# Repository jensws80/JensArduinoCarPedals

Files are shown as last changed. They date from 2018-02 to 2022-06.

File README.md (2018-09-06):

# JensArduinoCarPedals

Car Simulator pedals for Arduino, I work with occasionally to develop.
If you want to develop this project feel free to do pull request to this repository.

Things todo:
* Update to support never version of MHeironimus/ArduinoJoystickLibrary
* Work with better feeling in pedals
* Maybe modify code to use rX rY and rZ axis to better reflect usual pedals axis.

This Arduino pedals have gas, brake and clutch and use a Arduino (Windows native drivers) to connect to usb port.

# Parts you need to this project

1. Arduino Pro Micro or any board based on ATmega32U4
2. Usb cable between Arduino board and computer.
3. 3 piece Slide Potentiometer 5kohm or hall sensors.
4. 3 cheap styling pedals for cars.
5. Spring
6. Some metall to build pedal construction in
7. Nuts, bolts and cables to potentiometer

For this you need to download MHeironimus/ArduinoJoystickLibrary (LGPL-3.0) and my Arduino project

<A HREF="https://github.com/MHeironimus/ArduinoJoystickLibrary">MHeironimus/ArduinoJoystickLibrary Version 1.0</A><br>
<A HREF="https://github.com/jensws80/JensArduinoCarPedals">My Arduino file</A>

# Electrical drawings.
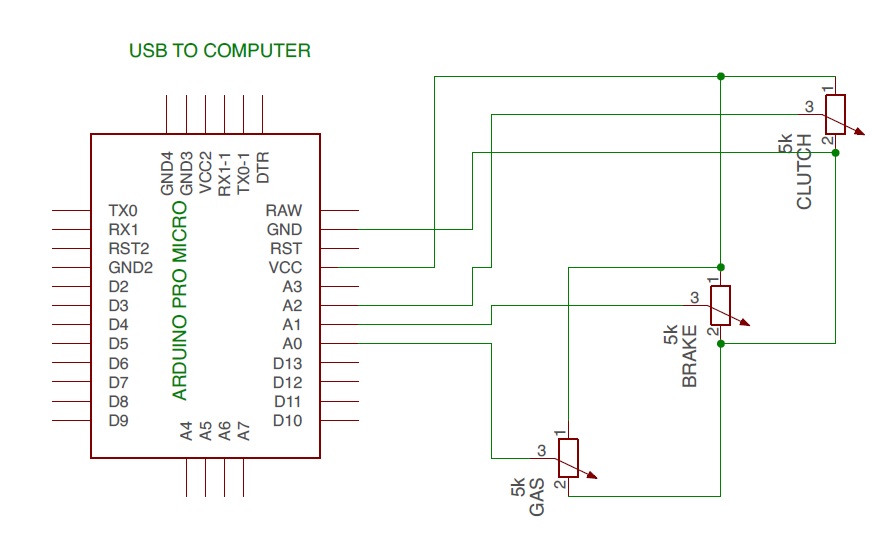
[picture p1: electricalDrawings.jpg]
</A>
Connect Gas to A0, Brake to A1 and Clutch to A2. Connect each potentiometer to +5v and GND

This electrical drawings in made in Eagle.

# Building Pedal construction

I build my pedal construction in steel and welding it together. One tricky part was to find spring with correct feeling. You have to test what you like. I also fond that 100mm from bottom to center of pedal was a good length for my foot.

Pedals drawings is done in Sketchup.

# Test run in Project Cars

See this Youtube clip

<A href="https://www.youtube.com/embed/U09LJFdwUUU">Youtube clip</A>

## License
This project is licensed under the terms of the GNU V.3 license.

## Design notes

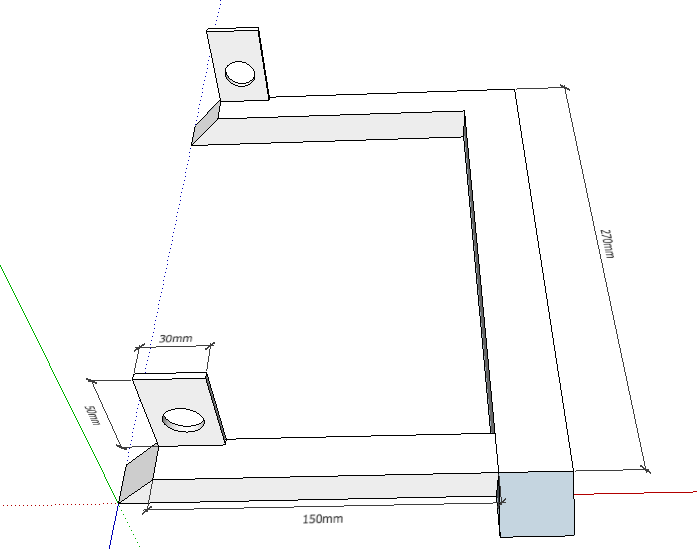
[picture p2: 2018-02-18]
pedalsPlate.png

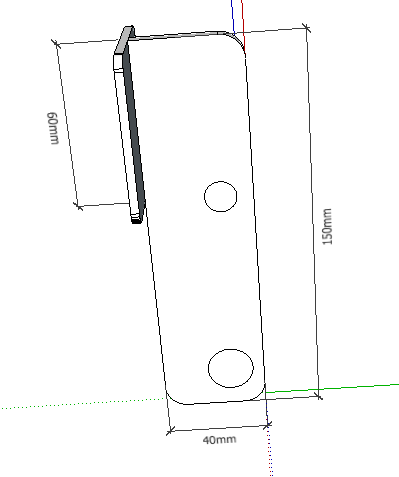
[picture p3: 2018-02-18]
pedals.png

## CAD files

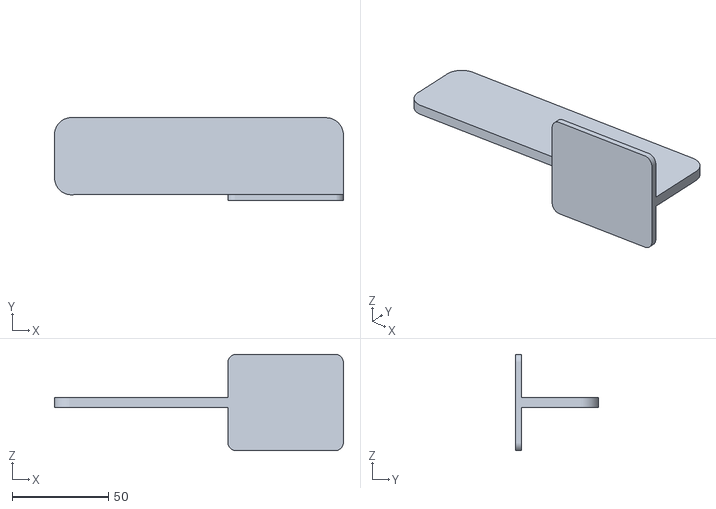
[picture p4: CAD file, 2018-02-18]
pedals.stl
150.1 x 43.1 x 50.1

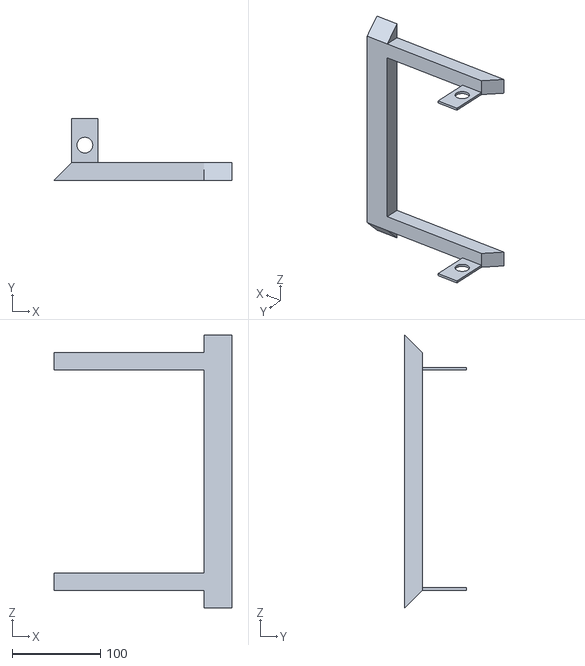
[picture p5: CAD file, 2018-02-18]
pedalsPlate.stl
202.0 x 70.0 x 310.0

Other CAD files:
pedals.skp
pedalsPlate.skp

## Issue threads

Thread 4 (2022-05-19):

A-B-C all are using same Throttle and Z Axis

Vorpalv2, 2022-05-19:
A-B-C all are using same Throttle and Z Axis. what could be the issue?

Closed 2022-06-01.

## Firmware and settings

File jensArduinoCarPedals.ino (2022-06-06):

// Jens Arduino Pedals
// This car simulator pedals program have gas, brake and clutch to connect to usb port.
// No extra drives need to be installed in windows to get this to work.
//
// NOTE: This file is for use with Arduino Leonardo and  Arduino Micro only.
//       Arduino Micro only.
//
// To get this program to work you need MHeironimus GPLv3 joystick libary from
// https://github.com/MHeironimus/ArduinoJoystickLibrary version-1.0
//
// by Jens Söderström jensws.com
// 2016-11-01
//
// This project is licensed under the terms of the GNU V.3 license.
//
//--------------------------------------------------------------------


#include <Joystick.h>

Joystick_ Joystick;

// Variable
int gas = A0;
int brake = A1; 
int clutch = A2;
int gasValue = 0;
int gasValuebyte = 0;
int brakeValue = 0;
int brakeValuebyte1 = 0;
int brakeValuebyte2 = 0;
int clutchValue = 0;
int clutchValuebyte1 = 0;
int clutchValuebyte2 = 0;

// init joystick libary
void setup() {
  Joystick.begin();
}

void loop() {
  
  // Gas
  gasValue = analogRead(gas);
  if (gasValue >= 1) {
  gasValuebyte = gasValue / 4 ;
   }
   else
   {
    gasValuebyte = 0 ;
   }
  Joystick.setThrottle(gasValuebyte);
  delay(1); 

  // Brake
  brakeValue = analogRead(brake);
  if (brakeValue >= 1) {
    brakeValuebyte1 = brakeValue / 4;
    brakeValuebyte2 = brakeValuebyte1 - 127;
  
   }
   else
   {
    brakeValuebyte2 = -127;
   }
  Joystick.setYAxis(brakeValuebyte2);
  delay(1); 

  // Clutch
  clutchValue = analogRead(clutch);
  if (clutchValue >= 1) {
  clutchValuebyte1 = clutchValue / 4;
  clutchValuebyte2 = clutchValuebyte1 - 127;
  
   }
   else
   {
    clutchValuebyte2 = -127;
   }
   Joystick.setZAxis(clutchValuebyte2);
  delay(1); 
}

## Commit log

2018-02-18 Initiale version 1.0
    [pedalElectricalDrawings.sch, pedals.skp, pedals.stl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]
2021-11-05 missing constructor for Joystick
    [jensArduinoCarPedals.ino]
